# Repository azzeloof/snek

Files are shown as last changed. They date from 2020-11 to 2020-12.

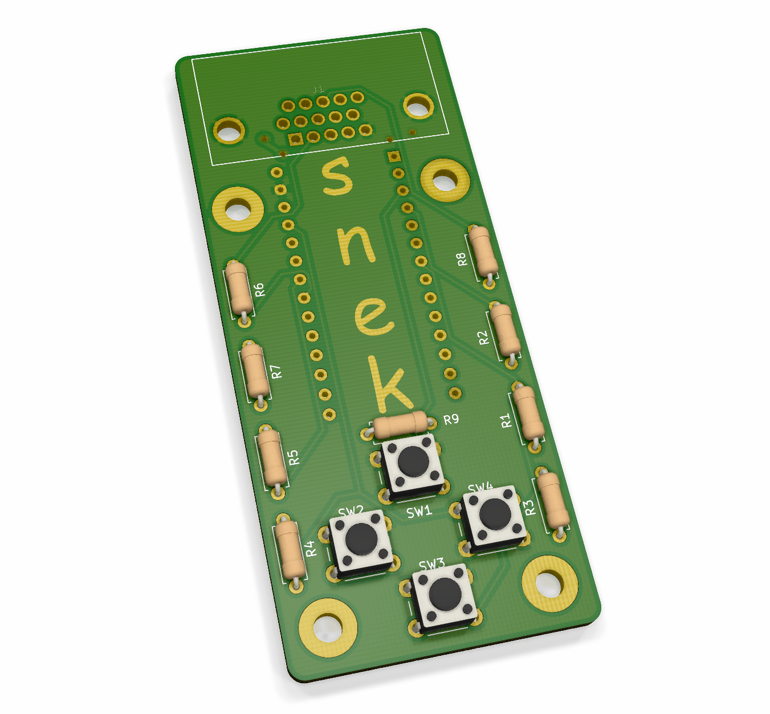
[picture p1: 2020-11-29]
hardware/snek.png

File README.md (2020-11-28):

# snek
This is a real hacky snake clone written in verilog over the course of 2.5 days for a game jam. It's designed for the TinyFPGA BX, but it should be easily extendable to other platforms by rewriting top.v.

The game is played via four pushbuttons connected to the FPGA, and video is output over VGA (640x480).

There's a python script (makesplash.py) for generating a splash screen binary from a png image. Just in case you want to replace my beautiful splashscreen art. One note- synthesis takes forever with complicated (not simple geometric) art. For debugging, I recommend commenting out the memory read in spash.v and assigning r, g, and b to 1 or 0. This will result in a simple, solid-color splash screen displayed while you wait for the monitor to realize it has a signal.

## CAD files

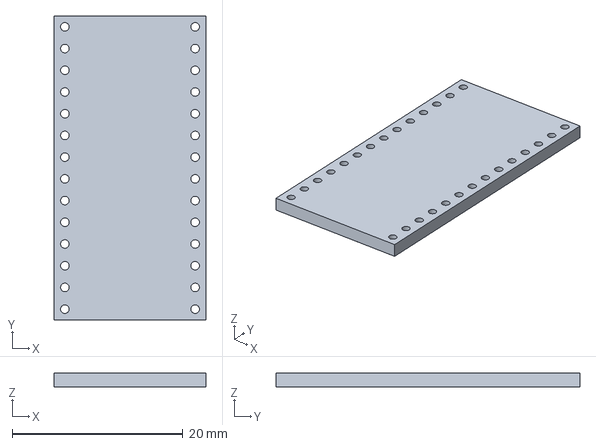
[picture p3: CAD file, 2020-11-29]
hardware/3d/TinyFPGA-BX.step
17.8 x 35.6 x 1.60 mm

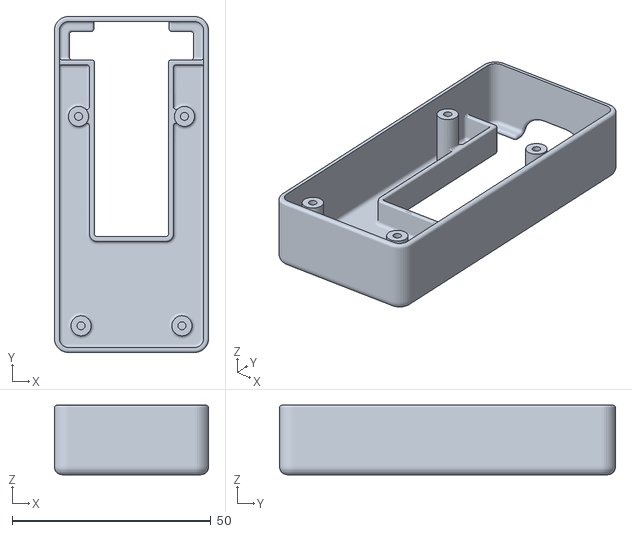
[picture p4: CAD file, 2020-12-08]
hardware/snek-case-r2.stl
38.9 x 84.6 x 17.5

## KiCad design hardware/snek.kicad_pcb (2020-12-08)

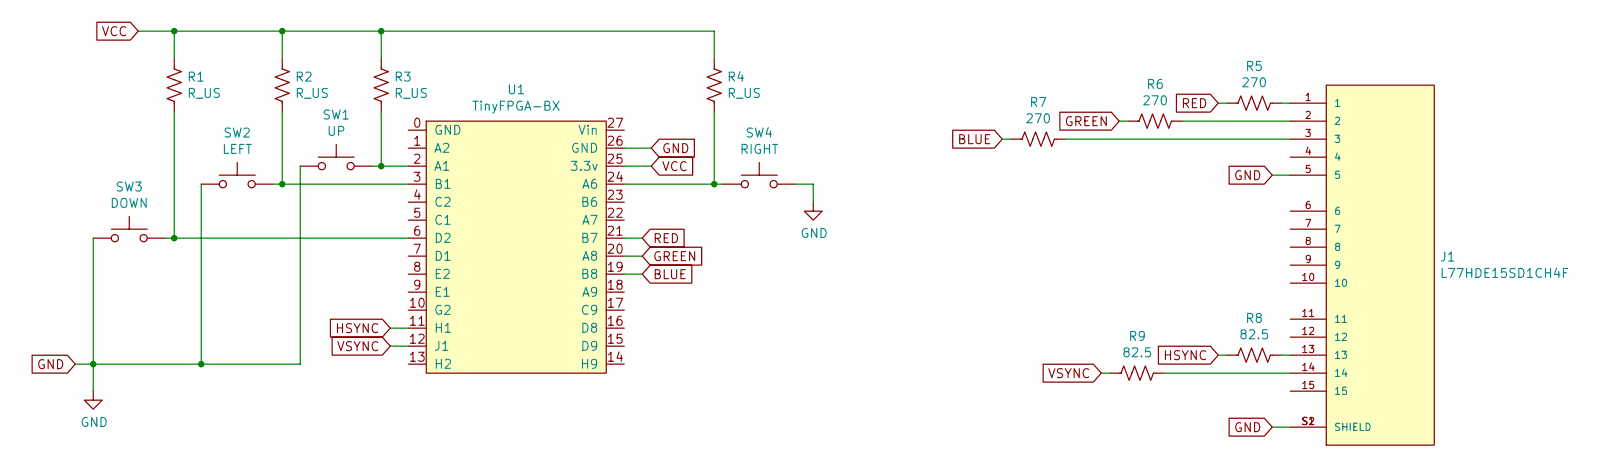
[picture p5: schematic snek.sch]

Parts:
J1: L77HDE15SD1CH4F; AMPHENOL_L77HDE15SD1CH4F; PARTREV N/A
R1, R2, R3, R4: R_US; R_Axial_DIN0207_L6.3mm_D2.5mm_P7.62mm_Horizontal
R5, R6, R7: 270; R_Axial_DIN0207_L6.3mm_D2.5mm_P7.62mm_Horizontal
R8, R9: 82.5; R_Axial_DIN0207_L6.3mm_D2.5mm_P7.62mm_Horizontal
SW1: UP; SW_PUSH_6mm
SW2: LEFT; SW_PUSH_6mm
SW3: DOWN; SW_PUSH_6mm
SW4: RIGHT; SW_PUSH_6mm
U1: TinyFPGA-BX

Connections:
BLUE: R7.2, U1.19 (B8)
GND: J1.5, J1.S1 (SHIELD), J1.S2 (SHIELD), SW1.1, SW2.1, SW3.1, SW4.2, U1.26 (GND)
GREEN: R6.2, U1.20 (A8)
HSYNC: R8.2, U1.11 (H1)
unnamed: J1.1, R5.1
unnamed: J1.2, R6.1
unnamed: J1.3, R7.1
unnamed: J1.13, R8.1
unnamed: J1.14, R9.1
unnamed: R1.2, SW3.2, U1.6 (D2)
unnamed: R2.2, SW2.2, U1.3 (B1)
unnamed: R3.2, SW1.2, U1.2 (A1)
unnamed: R4.2, SW4.1, U1.24 (A6)
RED: R5.2, U1.21 (B7)
VCC: R1.1, R2.1, R3.1, R4.1, U1.25 (3.3v)
VSYNC: R9.2, U1.12 (J1)

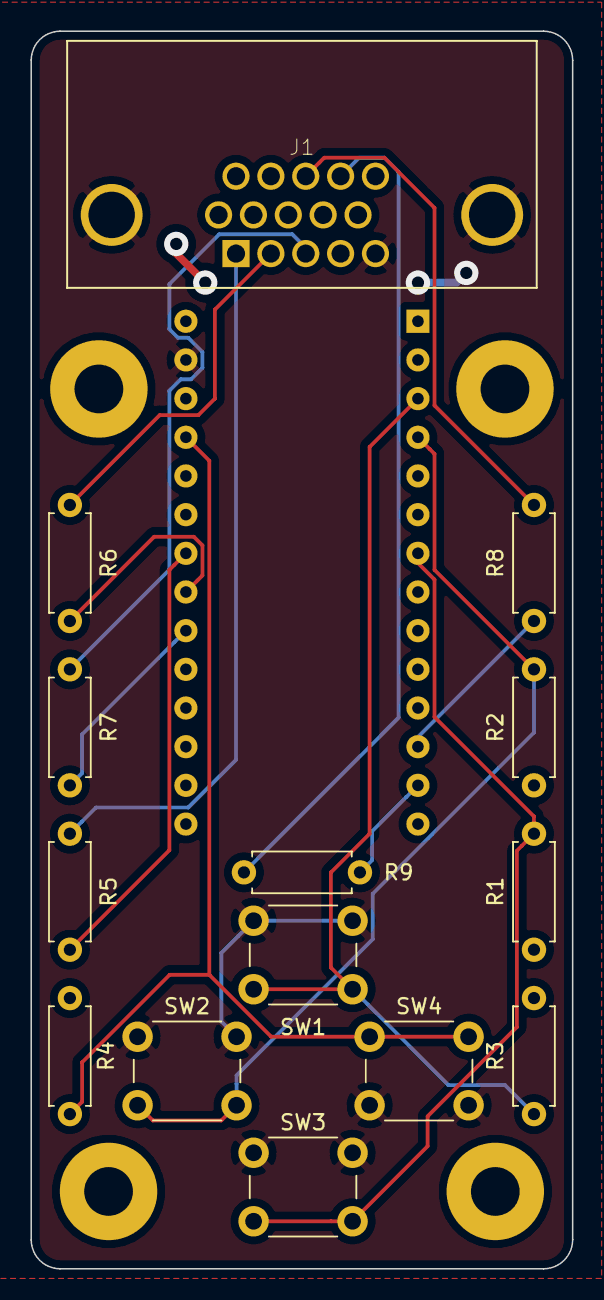
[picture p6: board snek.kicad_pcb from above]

Board: 2 copper layers, 35.6 x 81.3 mm, 15 parts (1 on the bottom side), 16 nets.

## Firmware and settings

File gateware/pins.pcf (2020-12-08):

###############################################################################
#
# TinyFPGA BX constraint file (.pcf)
#
###############################################################################
#
# Copyright (c) 2018, Luke Valenty
# All rights reserved.
# 
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
# THIS SOFTWARE IS PROVIDED BY THE COPYRIGHT HOLDERS AND CONTRIBUTORS "AS IS" AND
# ANY EXPRESS OR IMPLIED WARRANTIES, INCLUDING, BUT NOT LIMITED TO, THE IMPLIED
# WARRANTIES OF MERCHANTABILITY AND FITNESS FOR A PARTICULAR PURPOSE ARE
# DISCLAIMED. IN NO EVENT SHALL THE COPYRIGHT OWNER OR CONTRIBUTORS BE LIABLE FOR
# ANY DIRECT, INDIRECT, INCIDENTAL, SPECIAL, EXEMPLARY, OR CONSEQUENTIAL DAMAGES
# (INCLUDING, BUT NOT LIMITED TO, PROCUREMENT OF SUBSTITUTE GOODS OR SERVICES;
# LOSS OF USE, DATA, OR PROFITS; OR BUSINESS INTERRUPTION) HOWEVER CAUSED AND
# ON ANY THEORY OF LIABILITY, WHETHER IN CONTRACT, STRICT LIABILITY, OR TORT
# (INCLUDING NEGLIGENCE OR OTHERWISE) ARISING IN ANY WAY OUT OF THE USE OF THIS
# SOFTWARE, EVEN IF ADVISED OF THE POSSIBILITY OF SUCH DAMAGE.
#
# The views and conclusions contained in the software and documentation are those
# of the authors and should not be interpreted as representing official policies,
# either expressed or implied, of the <project name> project. 
#
###############################################################################

####
# TinyFPGA BX information: https://github.com/tinyfpga/TinyFPGA-BX/
####

# Left side of board
set_io --warn-no-port --warn-no-port PIN_1 A2
set_io --warn-no-port PIN_2 A1
set_io --warn-no-port PIN_3 B1
set_io --warn-no-port PIN_4 C2
set_io --warn-no-port PIN_5 C1
set_io --warn-no-port PIN_6 D2
set_io --warn-no-port PIN_7 D1
set_io --warn-no-port PIN_8 E2
set_io --warn-no-port PIN_9 E1
set_io --warn-no-port PIN_10 G2
set_io --warn-no-port PIN_11 H1
set_io --warn-no-port PIN_12 J1
set_io --warn-no-port PIN_13 H2

# Right side of board
set_io --warn-no-port PIN_14 H9
set_io --warn-no-port PIN_15 D9
set_io --warn-no-port PIN_16 D8
set_io --warn-no-port PIN_17 C9
set_io --warn-no-port PIN_18 A9
set_io --warn-no-port PIN_19 B8
set_io --warn-no-port PIN_20 A8
set_io --warn-no-port PIN_21 B7
set_io --warn-no-port PIN_22 A7
set_io --warn-no-port PIN_23 B6
set_io --warn-no-port PIN_24 A6

# SPI flash interface on bottom of board
set_io --warn-no-port SPI_SS F7
set_io --warn-no-port SPI_SCK G7
set_io --warn-no-port SPI_IO0 G6
set_io --warn-no-port SPI_IO1 H7
set_io --warn-no-port SPI_IO2 H4
set_io --warn-no-port SPI_IO3 J8

# General purpose pins on bottom of board
set_io --warn-no-port PIN_25 G1
set_io --warn-no-port PIN_26 J3
set_io --warn-no-port PIN_27 J4
set_io --warn-no-port PIN_28 G9
set_io --warn-no-port PIN_29 J9
set_io --warn-no-port PIN_30 E8
set_io --warn-no-port PIN_31 J2

# LED
set_io --warn-no-port LED B3

# USB
set_io --warn-no-port USBP B4
set_io --warn-no-port USBN A4
set_io --warn-no-port USBPU A3

# 16MHz clock
set_io --warn-no-port CLK B2 # input

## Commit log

2020-11-29 designed a PCB for some reason
    [TinyFPGA-BX.step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]
2020-11-30 cleaned up KiCad files
2020-12-08 fixed visual artifacts, restructured
    [pins.pcf]
2020-12-08 Updated 3d printed case
    [snek-case-r1.stl, snek-case-r2.stl, snek.kicad_pcb]
